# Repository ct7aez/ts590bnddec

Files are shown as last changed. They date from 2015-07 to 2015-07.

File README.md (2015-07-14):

# ts590bnddec
Arduino based KNW TS-590 Band Decoder.
This is the pcb and sch design for the TS-590S(G) Arduino based Band Decoder.
Based on the ground breaking work from Ondrej Kolonicny, OK1CDJ.
Made by João Cunha Lopes, CT2HME and Pedro Correia, CT7AEZ.
This device can read from the radio serial port is frequency and gives the Yaesu BCD and ICOM voltage output.  It has already implementations for the I2C protocol in ways to communicate with other devices like an switch box or relay driver.
Also you can connect a LCD display (arduino LiquidCrystal or I2C).
There are four buttons that can be used for the config menu.

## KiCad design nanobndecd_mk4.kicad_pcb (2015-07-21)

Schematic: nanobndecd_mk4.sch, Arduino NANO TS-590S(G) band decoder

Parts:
C1, C2: 4n7; C_0805_HandSoldering
C3: 330n; C_1812_HandSoldering
C4: 100n; C_0805_HandSoldering
C5: 220u; C_Radial_D5_L11_P2.5
C6, C8, C9, C10, C11, C12, C13, C14, C21, C22, C23, C24: 10n; C_0805_HandSoldering
C7: 2u2; C_Radial_D5_L11_P2.5
C15, C16, C17, C18, C19: 1u; C_Radial_D5_L11_P2.5
CON1: 5,5/2,1mm; BARREL_JACK
D1, D2, D4, D5: 1N5817; Diode_DO-41_SOD81_Horizontal_RM10
D3: 1.5KE20A; Diode_DO-201AD_Horizontal_RM15
D6: 1N959B; Diode_DO-35_SOD27_Horizontal_RM10
F1: 500mAT; Fuseholder5x20_horiz_open_inline_Type-I
J1, J2: RJ45; RJ45_8
J3: DB9; DB9FC
JP1: Jumper_NC_Small; Pin_Header_Straight_1x02
L1, L2: 100u; Choke_Horizontal_RM10mm
P1, P2: CONN_01X16; Socket_Strip_Straight_1x16
P3: CONN_02X08; Pin_Header_Straight_2x08
P4: CONN_01X04; Pin_Header_Straight_1x04
Q1, Q2: BS170; TO-92_Inline_Wide
R1: 12K; R_0805_HandSoldering
R2: 20K; R_0805_HandSoldering
R3: 240R; R_0805_HandSoldering
R4, R5: 2K; R_0805_HandSoldering
RV1: 10K; Potentiometer_Trimmer-Piher-PT15-h2-5_vertical
SW1: DOWN; SW_SPST_PTS645
SW2: UP; SW_SPST_PTS645
SW3: SELECT; SW_SPST_PTS645
SW4: ESC; SW_SPST_PTS645
U1: LM7805CT; TO-220_Neutral123_Vertical_LargePads
U2: MAX232; DIP-16__300_ELL

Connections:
+5V: C19.1, D4.2, D5.2, J1.6, P3.2, P3.15, P4.3, R4.1, R5.1, RV1.1, U2.16 (VCC)
+5VA: D5.1, P2.4
+5VD: C4.1, C5.1, D4.1, U1.3
/13,8V: C2.1, D1.1, J2.6
/ACC2_PWM: P1.9, Q1.2
/BCKL: P2.11, Q2.2
/BCKLa: P3.16, Q2.1
/BND_A: C12.1, J2.1, P2.5
/BND_B: C9.1, J2.3, P2.6
/BND_C: C13.1, J2.5, P2.7
/BND_D: C10.1, J2.7, P2.8
/D2: P1.5, P3.14
/D3: P1.6, P3.13
/D4: P1.7, P3.12
/D5: P1.8, P3.11
/D11: P1.14, P3.6
/D12: P1.15, P3.4
/EXT_SCL: C11.1, J1.5, P2.10, P4.2, R5.2
/EXT_SDA: C14.1, J1.4, P2.9, P4.1, R4.2
/ICOM_BND: C6.1, C7.1, D6.2, J2.4, R1.1, R3.1
/RX: P1.2, U2.12 (R1OUT)
/RX232: C21.2, L2.1, U2.13 (R1IN)
/SW1: P1.10, P3.7, SW1.1
/SW2: P1.11, P3.8, SW2.1
/SW3: P1.12, P3.9, SW3.1
/SW4: P1.13, P3.10, SW4.1
/TX: P1.1, U2.11 (T1IN)
/TX232: C22.2, L1.1, U2.14 (T1OUT)
/TX_ENBL: C8.1, J2.2, P2.15
/VO: P3.3, RV1.2
GND: C1.2, C2.2, C3.2, C4.2, C5.2, C6.2, C7.2, C8.2, C9.2, C10.2, C11.2, C12.2, C13.2, C14.2, C17.2, C18.1, C19.2, C21.1, C22.1, C23.2, C24.2, CON1.2, D3.1, D6.1, J1.3, J2.8, J3.5, P1.4, P2.2, P3.1, P3.5, P4.4, Q2.3, R2.2, RV1.3, SW1.2, SW2.2, SW3.2, SW4.2, U1.2, U2.15 (GND)
unnamed: C1.1, CON1.1, D2.1
unnamed: C15.1, U2.1 (C1+)
unnamed: C15.2, U2.3 (C1-)
unnamed: C16.1, U2.4 (C2+)
unnamed: C16.2, U2.5 (C2-)
unnamed: C17.1, U2.2 (V+)
unnamed: C18.2, U2.6 (V-)
unnamed: C23.1, J3.3, J3.6, L1.2
unnamed: C24.1, J3.1, J3.2, L2.2
unnamed: D1.2, D2.2, F1.1
unnamed: J3.7, JP1.1
unnamed: J3.8, JP1.2
unnamed: P2.12, R1.2, R2.1
unnamed: Q1.3, R3.2
VCC: C3.1, D3.2, F1.2, P2.1, Q1.1, U1.1

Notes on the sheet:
Arduino NANO goes here
Max. 19VDC Min. 9VDC
Use JP2 when using a stock straigth cable
1-D1/TX--TX 2-D0/RX--RX 3-RESET--RESET 4-GND--GND 5-D2--DISPLAY D7 (OUT) 6-D3--DISPLAY D6 (OUT) 7-D4--DISPLAY D5 (OUT) 8-D5--DISPLAY D4 (OUT) 9-D6--ACC_PWM (OUT PWM) 10-D7--SW1 DOWN (INP) 11-D8--SW2 UP (INP) 12-D9--SW3 SELECT (INP) 13-D10--SW4 ESC (INP) 14-D11--DISPLAYENABLE (OUT) 15-D12--DISPLAY RS
30-VIN--VCC 29-GND--GND 28-RESET--RESET 27-+5V--TO +5VA (INP/OUT) 26-A0--YAESU BAND DATA A (INP/OUT) 25-A1--YAESU BAND DATA B (INP/OUT) 24-A2--YAESU BAND DATA C (INP/OUT) 23-A3--YAESU BAND DATA D (INP/OUT) 22-A4--EXT_SDA (I2C) 21-A5--EXT_SCL (I2C) 20-A6--BCKL (OUT) 19-A7--ICOM_BND (ANALOG INP) 18-A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
x .6 divider
I2C Pull Up
NSR 6 Pin
NSR 4 Pin
NSR 2 Pin

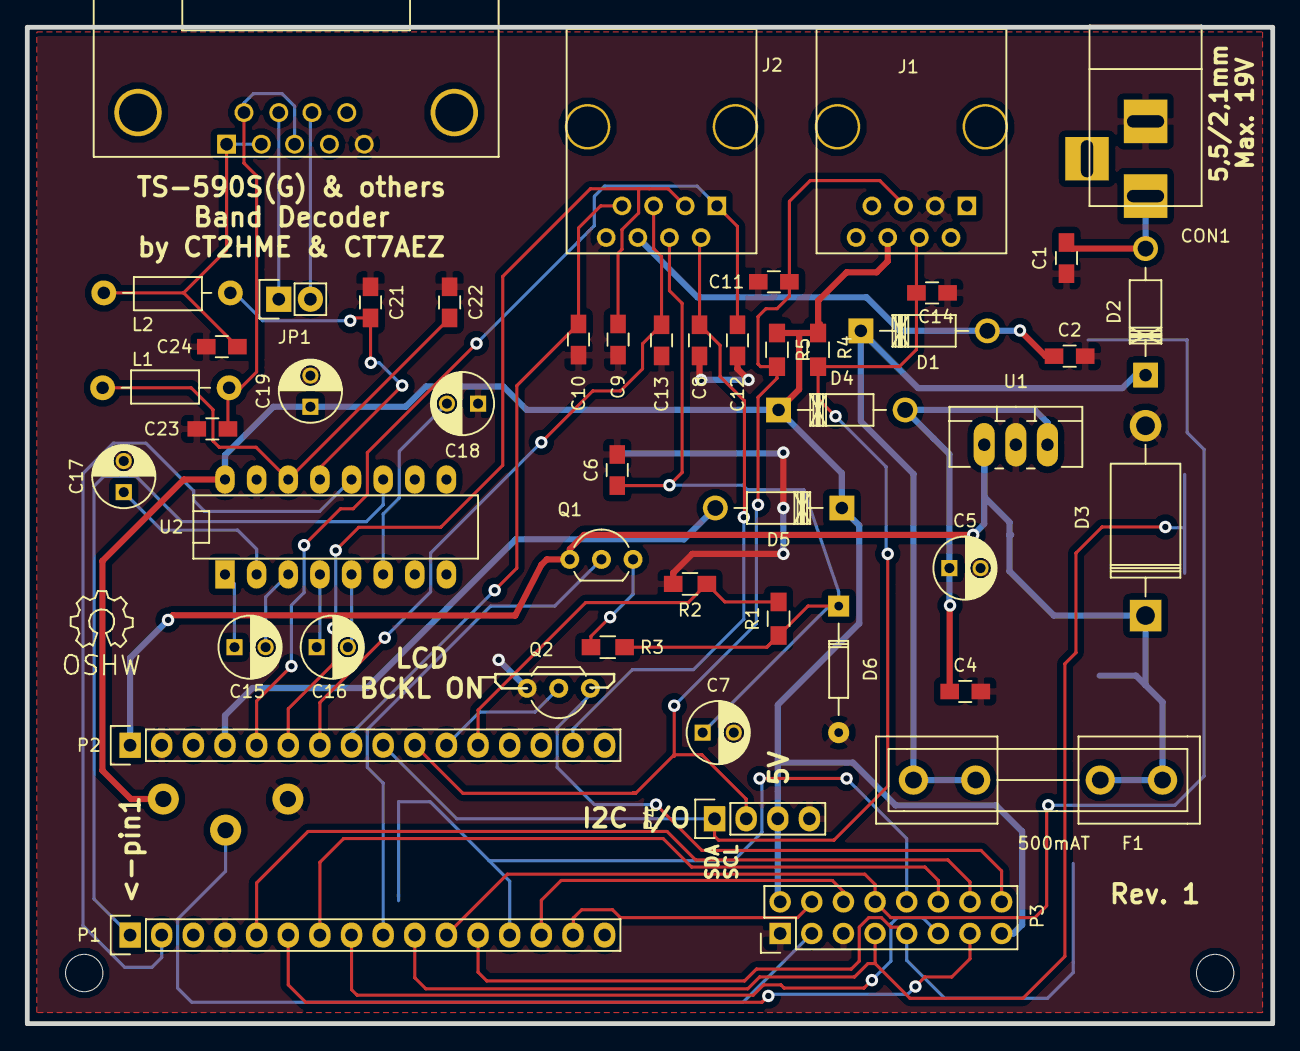
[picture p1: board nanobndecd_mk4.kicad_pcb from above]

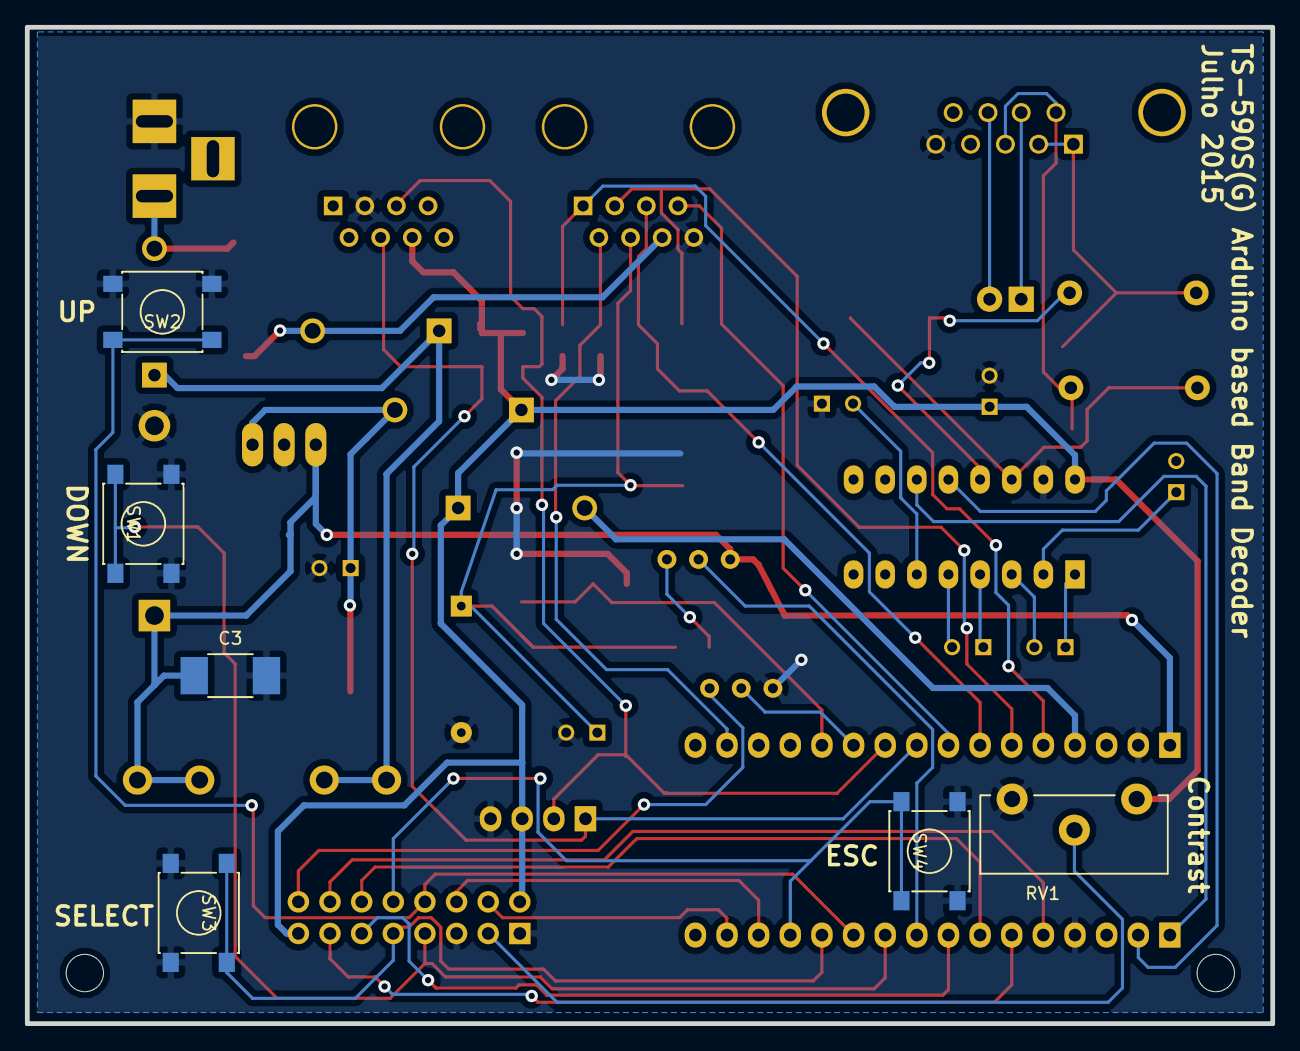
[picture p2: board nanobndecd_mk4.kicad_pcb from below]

Board: 2 copper layers, 100.0 x 80.0 mm, 55 parts (6 on the bottom side), 46 nets.

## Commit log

2015-07-14 kick off
    [nanobndecd_mk4.kicad_pcb, nanobndecd_mk4.sch]
2015-07-14 Ver. 1 revision for Kicad 2015-06-24 BZR 5815
    [nanobndecd_mk4.kicad_pcb, nanobndecd_mk4.sch]
2015-07-14 Final PCB
    [nanobndecd_mk4.kicad_pcb]
2015-07-15 CC licence added
    [nanobndecd_mk4.kicad_pcb, nanobndecd_mk4.sch]
2015-07-15 CC update
    [nanobndecd_mk4.kicad_pcb, nanobndecd_mk4.sch]
2015-07-18 Corrected U1 footprint
    [nanobndecd_mk4.kicad_pcb, nanobndecd_mk4.sch]
2015-07-19 Corrected P4 to pin header
    [nanobndecd_mk4.kicad_pcb, nanobndecd_mk4.sch]
2015-07-21 pcb text update
    [nanobndecd_mk4.kicad_pcb]

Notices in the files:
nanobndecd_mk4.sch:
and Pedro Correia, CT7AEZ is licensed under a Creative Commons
